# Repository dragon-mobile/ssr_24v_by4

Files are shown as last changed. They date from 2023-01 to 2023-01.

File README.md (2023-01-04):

# Solid State Relays - 24Volts by 4

<br/>



<br/>

The SSR 24Volts by 4 board is one of the open hardware solid state relay
PCB of my Dragon Mobile GitHub organization with a goal to make useful
hardware with associated firmware and software for the tiny home, van life
and maker communities.

## Contributing

Contributors are welcome.
Please note that this project has a [Contributor Covenant Code of Conduct].
By participating in this project you agree to abide by its terms.

All intentionally contributed hardware will be considered to be contributed
under the [CERN] license without any additional terms or conditions.

All intentionally contributed code will be considered to be contributed
under a [MIT] license without any additional terms or conditions.
Please include your information in a comment on all code files for the copyright
etc.

All intentionally contributed documentation, CAD files and libraries, footprints,
artwork or non-code text like this README etc. will be considered to be
contributed under the same [CC-BY-SA] license without any additional terms or
conditions.

Pull requests are always welcome. For major changes, please open an issue first
to discuss what you would like to change.
Please make sure to update or add tests as appropriate for all software changes.

## Licenses

GitHub<br/>

All hardware is licensed under the

  * [CERN] - CERN-OHL-W-2.0
  
You can find a copy of the CERN Open Hardware License - Weakly-reciprocal v2.0
in the [LICENSE-CERN-OHL-W-2] file and the how-to guide in the
[CERN-HOWTO_GUIDE] file.

All code is licensed under the

  * [MIT] - MIT License

You can find a copy of the license in the [LICENSE-MIT] file.

All documentation like this README is licensed under the Creative Commons
Attribution-ShareAlike 4.0 International License (CC-BY-SA).

All original CAD files and libraries, footprints, and artwork are also licensed
under the
Creative Commons Attribution-ShareAlike 4.0 International License (CC-BY-SA).
You can find a copy of the [CC-BY-SA] license in the [LICENSE-CC-BY-SA] file.

If after reading the above license files, how-tos, and related FAQs on the
linked license sites on how they apply to the project please either open an
issue or contact me (Michael Cummings) via my Github email and I will try
to guided you through my understanding of how it works.

[CC-BY-SA]: http://creativecommons.org/licenses/by-sa/4.0/
[CERN]: https://ohwr.org/project/cernohl/wikis/Documents/CERN-OHL-version-2
[CERN-HOWTO_GUIDE]: docs/cern_ohl_w_v2_howto.pdf
[Contributor Covenant Code of Conduct]: CODE_OF_CONDUCT.md 
[LICENSE-CC-BY-SA]: LICENSE-CC-BY-SA
[LICENSE-CERN-OHL-W-2]: CERN-OHL-W-2
[LICENSE-MIT]: LICENSE-MIT
[MIT]: https://opensource.org/licenses/MIT

<hr>
Copyright &copy; 2022, Michael Cummings<br/>
<a rel="license" href="http://creativecommons.org/licenses/by-sa/4.0/">

</a>

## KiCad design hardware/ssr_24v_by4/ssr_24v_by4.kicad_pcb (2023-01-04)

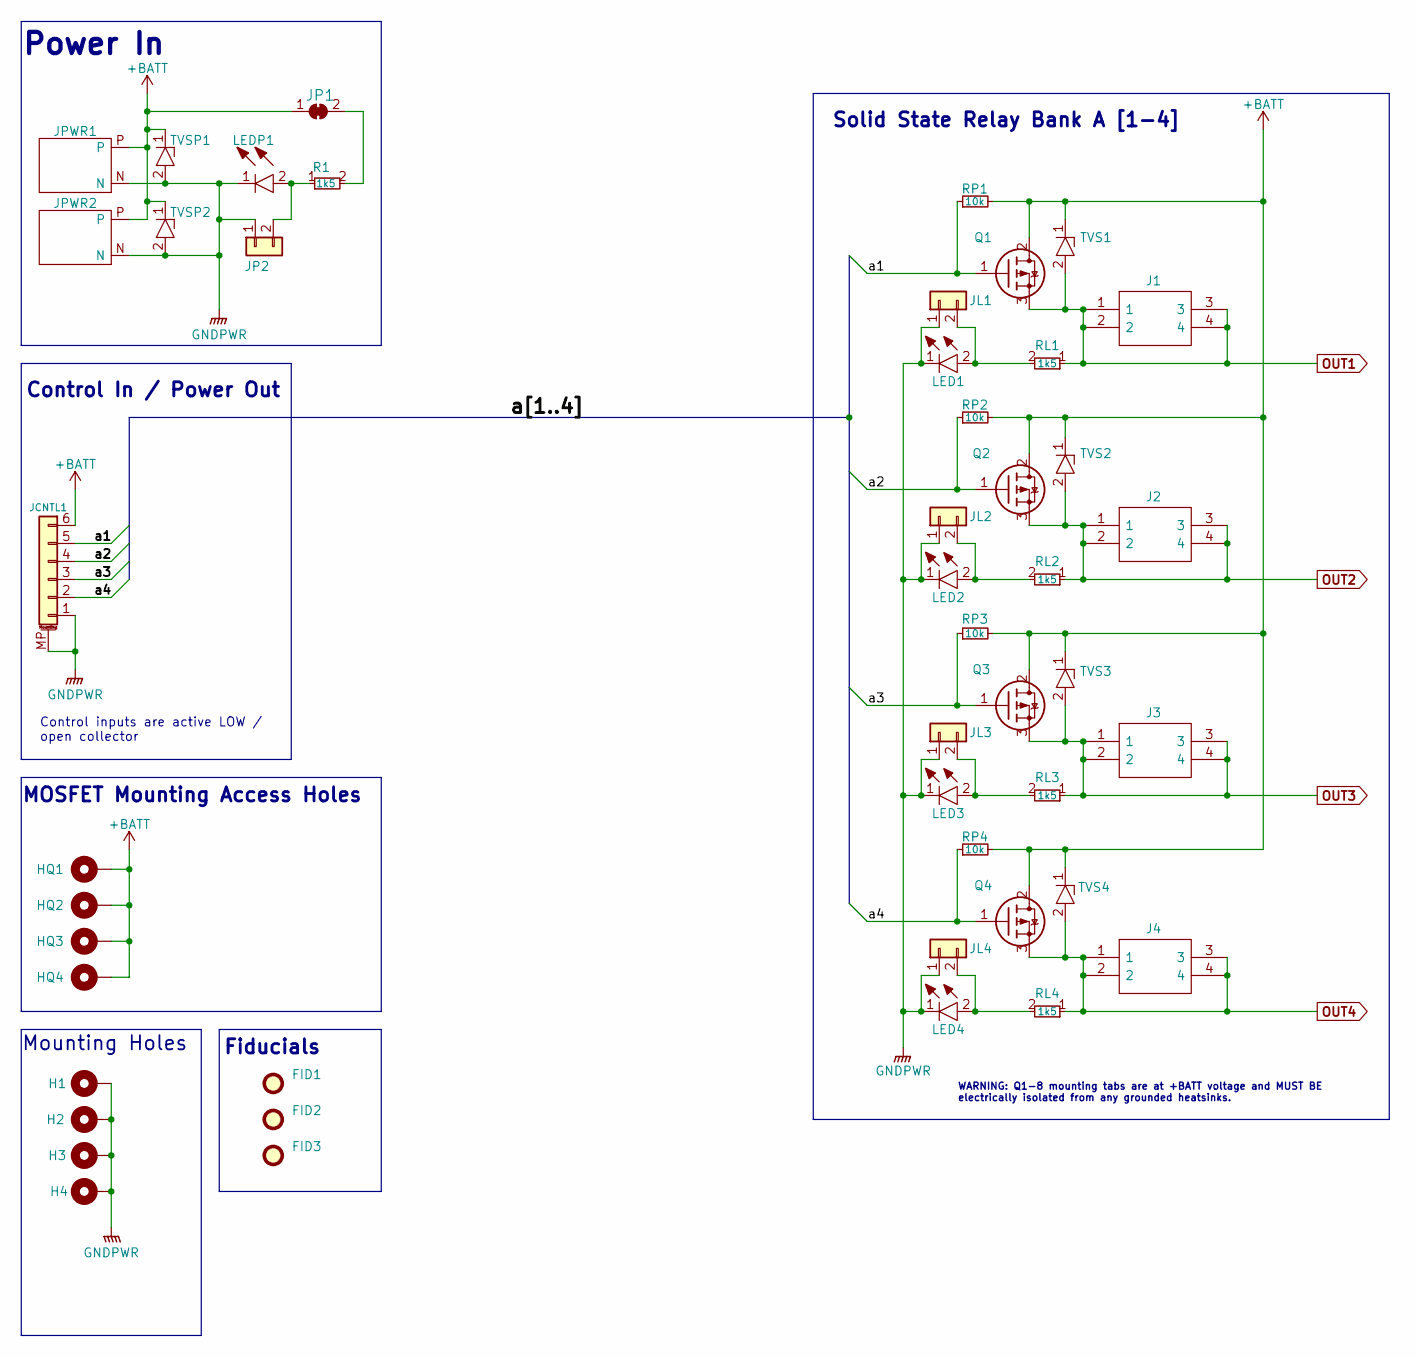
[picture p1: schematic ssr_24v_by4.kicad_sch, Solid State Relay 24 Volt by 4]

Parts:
FID1, FID2, FID3: Fiducial; Fiducial_0.5mm_Mask1mm
H1, H2, H3, H4: MountingHole; MountingHole_3.2mm_M3_Pad_Via
HQ1, HQ2, HQ3, HQ4: Access Hole; MountingHole_6.1mm_Pad_Via
J1, J2, J3, J4: 1190297; Mouser Part Number 651-1190297
JCNTL1: JST_GH_01x6_MountingPins; JST_GH_SM06B-GHS-TB_1x06-1MP_P1.25mm_Horizontal
JL1, JL2, JL3, JL4: Conn_01x02; PinHeader_1x02_P1.00mm_Vertical
JP1: SolderJumper_2_Bridged; SolderJumper-2_P1.3mm_Bridged_RoundedPad1.0x1.5mm
JP2: Conn_01x02; PinHeader_1x02_P1.00mm_Vertical
JPWR1, JPWR2: XT60PW-M; XT60PWM
LED1, LED2, LED3, LED4: LTST-C190KFKT; LEDC1607X80N; Mouser Part Number 859-LTST-C190KFKT
LEDP1: LTST-C190KGKT; LEDC1608X80N; Mouser Part Number 859-LTST-C190KGKT
Q1, Q2, Q3, Q4: IRF4905PBF; TO254P469X1042X1967-3P; Mouser Part Number 942-IRF4905PBF
R1: 1k5; RESC2012X65N; Mouser Part Number 755-SDR10EZPJ152
RL1, RL2, RL3, RL4: 1k5; RESC2012X65N; Mouser Part Number 755-SDR10EZPJ152
RP1, RP2, RP3, RP4: 10k; RESC2012X65N; Mouser Part Number 755-SDR03EZPJ103
TVS1, TVS2, TVS3, TVS4: SM6T33AY; SMBJ36CATR; Mouser Part Number 511-SM6T33AY
TVSP1, TVSP2: SM6T33AY; SMBJ36CATR; Mouser Part Number 511-SM6T33AY

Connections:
+BATT: HQ1.1, HQ2.1, HQ3.1, HQ4.1, JCNTL1.6, JP1.1 (A), JPWR1.P, JPWR2.P, Q1.2, Q2.2, Q3.2, Q4.2, RP1.2, RP2.2, RP3.2, RP4.2, TVS1.1, TVS2.1, TVS3.1, TVS4.1, TVSP1.1, TVSP2.1
/a1: JCNTL1.5, Q1.1, RP1.1
/a2: JCNTL1.4, Q2.1, RP2.1
/a3: JCNTL1.3, Q3.1, RP3.1
/a4: JCNTL1.2, Q4.1, RP4.1
GNDPWR: H1.1, H2.1, H3.1, H4.1, JCNTL1.1, JCNTL1.MP (MountPin), JL1.1, JL2.1, JL3.1, JL4.1, JP2.1, JPWR1.N, JPWR2.N, LED1.1, LED2.1, LED3.1, LED4.1, LEDP1.1, TVSP1.2, TVSP2.2
unnamed: JL1.2, LED1.2, RL1.2
unnamed: JL2.2, LED2.2, RL2.2
unnamed: JL3.2, LED3.2, RL3.2
unnamed: JL4.2, LED4.2, RL4.2
unnamed: JP1.2 (B), R1.2
unnamed: JP2.2, LEDP1.2, R1.1
OUT1: J1.1, J1.2, J1.3, J1.4, Q1.3, RL1.1, TVS1.2
OUT2: J2.1, J2.2, J2.3, J2.4, Q2.3, RL2.1, TVS2.2
OUT3: J3.1, J3.2, J3.3, J3.4, Q3.3, RL3.1, TVS3.2
OUT4: J4.1, J4.2, J4.3, J4.4, Q4.3, RL4.1, TVS4.2

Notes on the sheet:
WARNING: Q1-8 mounting tabs are at +BATT voltage and MUST BE electrically isolated from any grounded heatsinks.
MOSFET Mounting Access Holes
Control inputs are active LOW / open collector
Control In / Power Out
Power In
Fiducials
Mounting Holes
Solid State Relay Bank A [1-4]

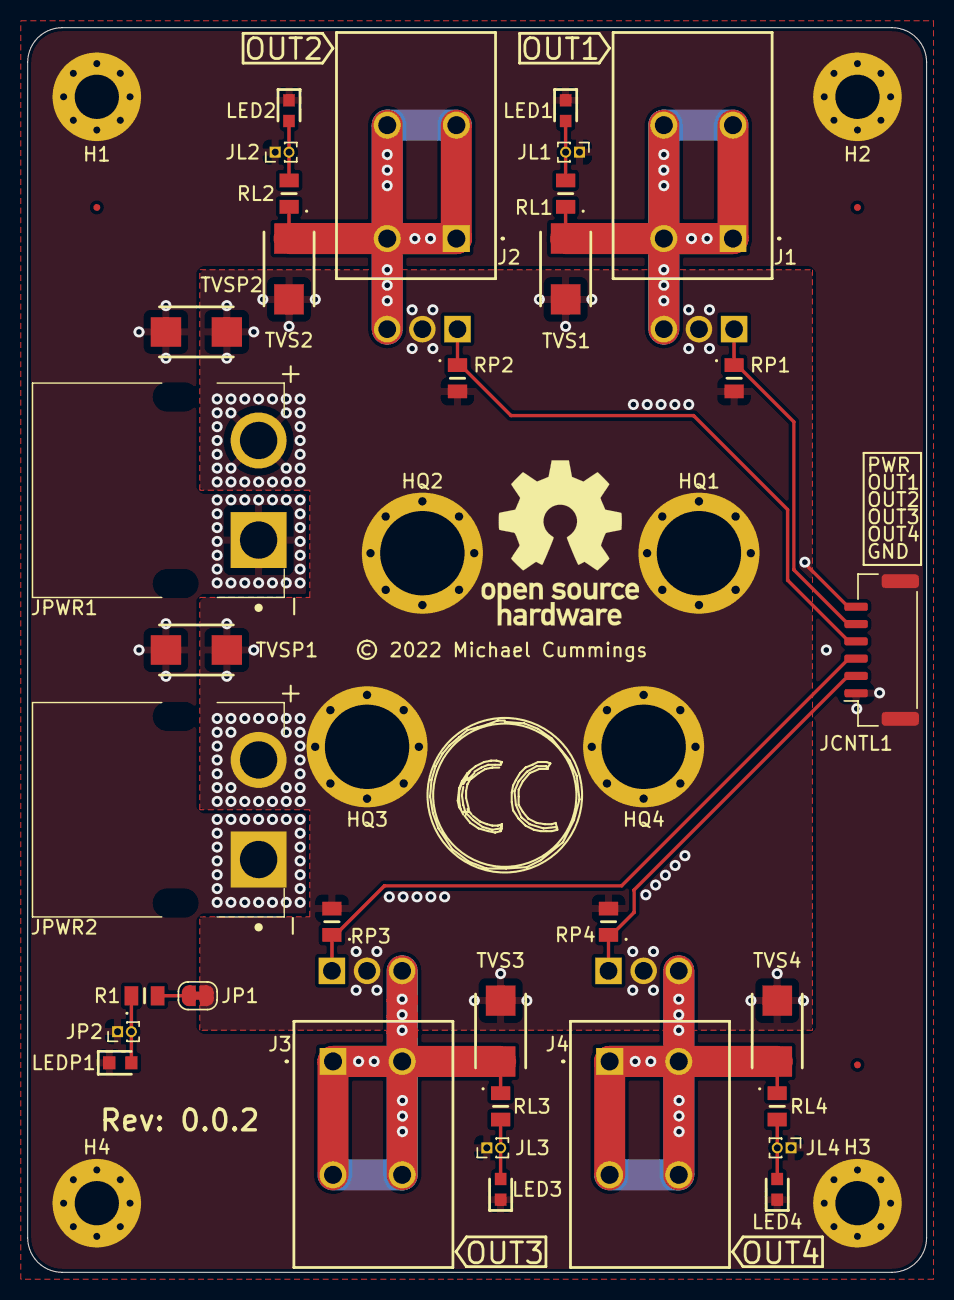
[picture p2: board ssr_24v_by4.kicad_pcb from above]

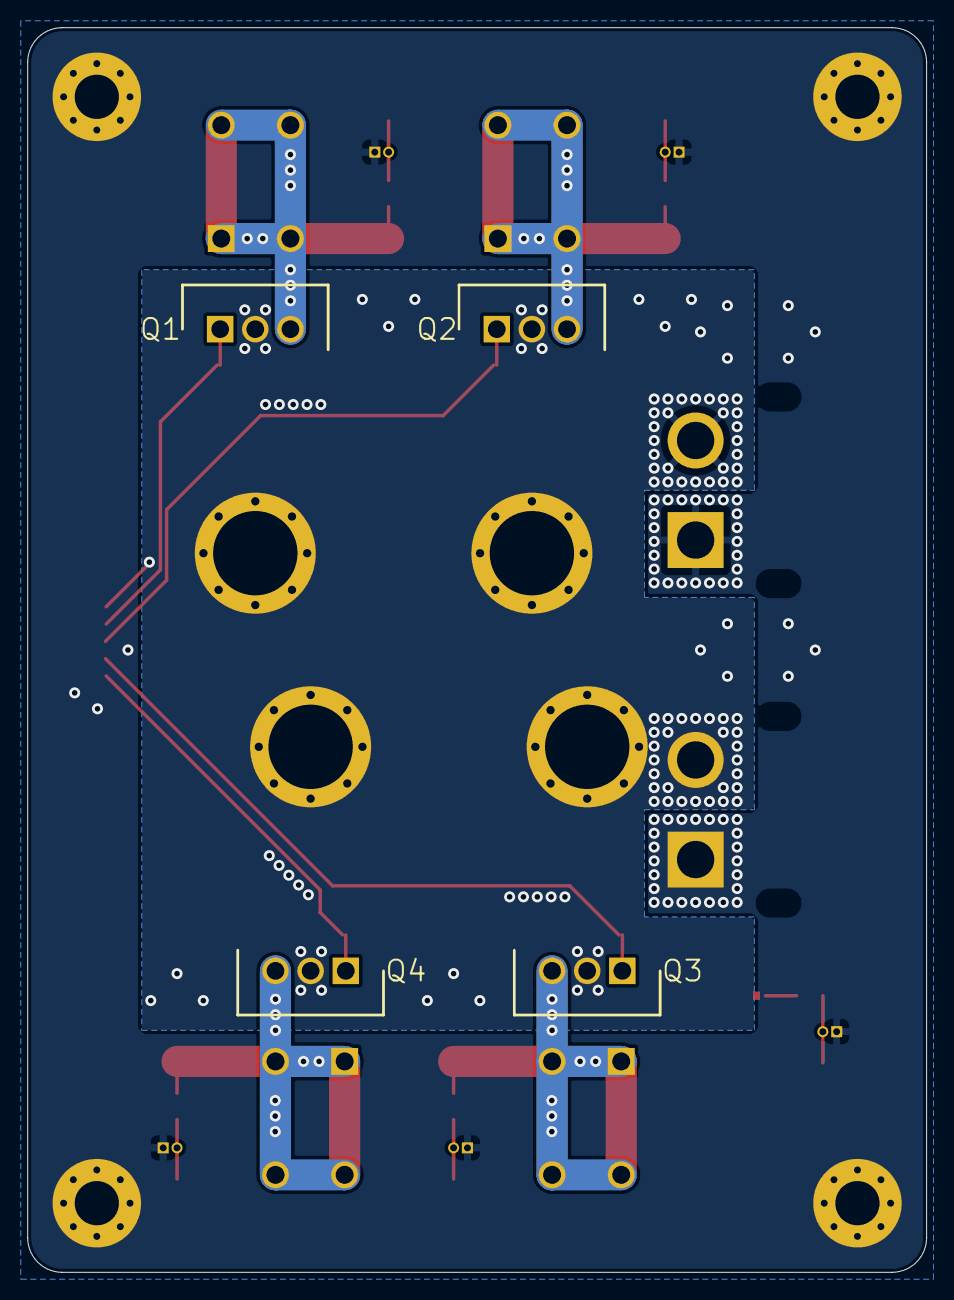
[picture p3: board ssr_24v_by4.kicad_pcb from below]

Board: 2 copper layers, 65.0 x 90.0 mm, 48 parts (4 on the bottom side), 16 nets.

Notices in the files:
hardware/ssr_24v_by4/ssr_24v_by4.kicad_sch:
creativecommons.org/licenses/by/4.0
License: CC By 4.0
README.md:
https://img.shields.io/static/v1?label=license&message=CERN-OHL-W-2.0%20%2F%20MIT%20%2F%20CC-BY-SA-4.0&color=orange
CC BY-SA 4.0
